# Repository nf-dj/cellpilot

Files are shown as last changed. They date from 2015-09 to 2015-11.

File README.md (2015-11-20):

# CellPilot

A controller to pilot UAV/drones via 3G/4G cellular connection.

WARNING: this version of CellPilot will soon be replaced by a new controller using TinyCom instead of Raspberry Pi (http://github.com/nfco/tinycom).

## Pictures

A view of the PCB, a Raspberry Pi "hat":

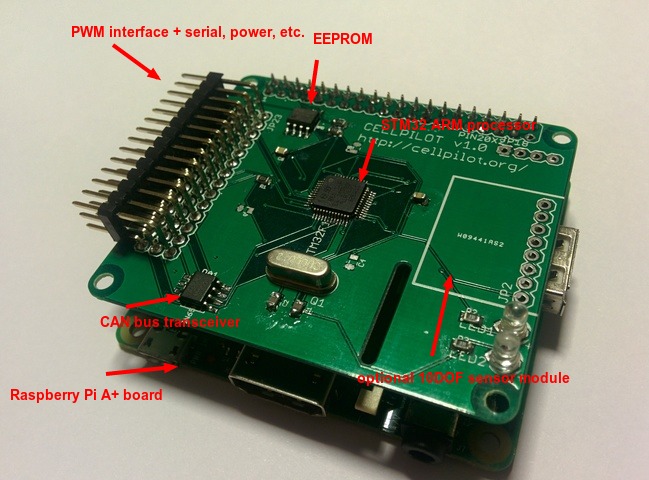
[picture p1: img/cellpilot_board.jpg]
CellPilot board


Inside a 3d-printed prototype box:

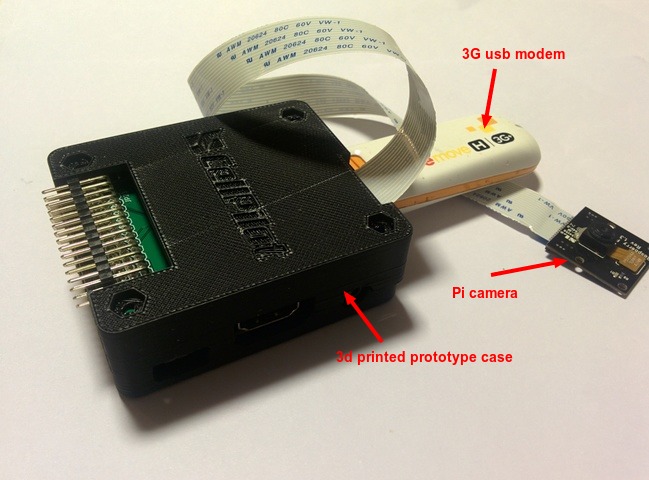
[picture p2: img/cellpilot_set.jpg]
CellPilot set


CellPilot installed on a DIY drone:

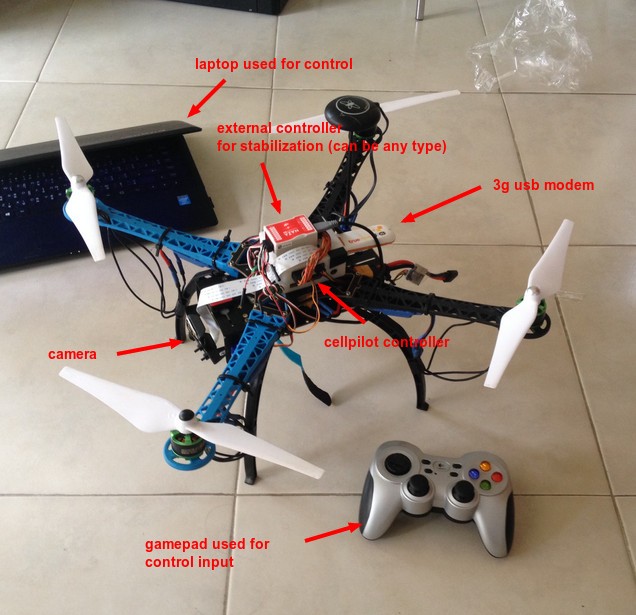
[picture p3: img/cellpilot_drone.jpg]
CellPilot drone


We still rely on an external controller for stabilization.
But a 10DOF sensor module can be installed on the CellPilot board and we can later try to do the stabilization directly on the STM32 processor of the board. (a prototype firmware to do this is already in the repository)

## Video

CellPilot test flight (64Kbps, 10fps):

CellPilot test flight (http://www.youtube.com/watch?v=GPAqMF_AkHQ)

(the strange colors in the video are due to the PiNoir camera, we will make a new video with a regular Pi camera and some vibration dampening)

## Ordering

A 3d-printed plastic case can be ordered here:
https://www.shapeways.com/shops/netforce

CellPilot case

## Contact

Send email to dj@netforce.com.

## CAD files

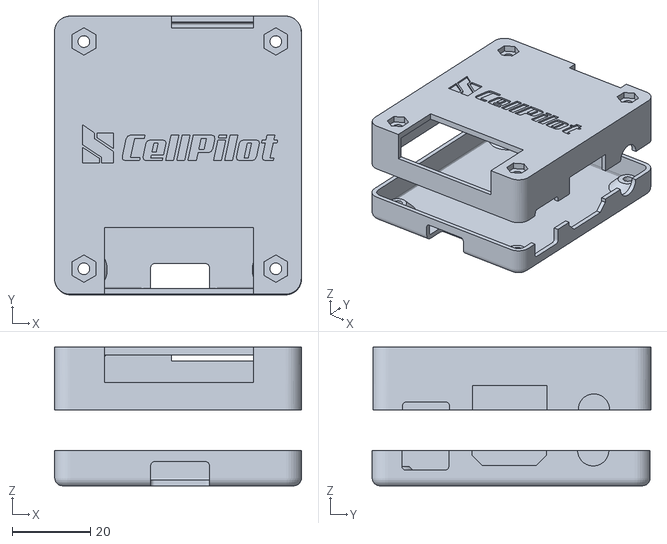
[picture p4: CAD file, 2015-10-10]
case/cellpilot_case.stl
63.1 x 71.2 x 35.4

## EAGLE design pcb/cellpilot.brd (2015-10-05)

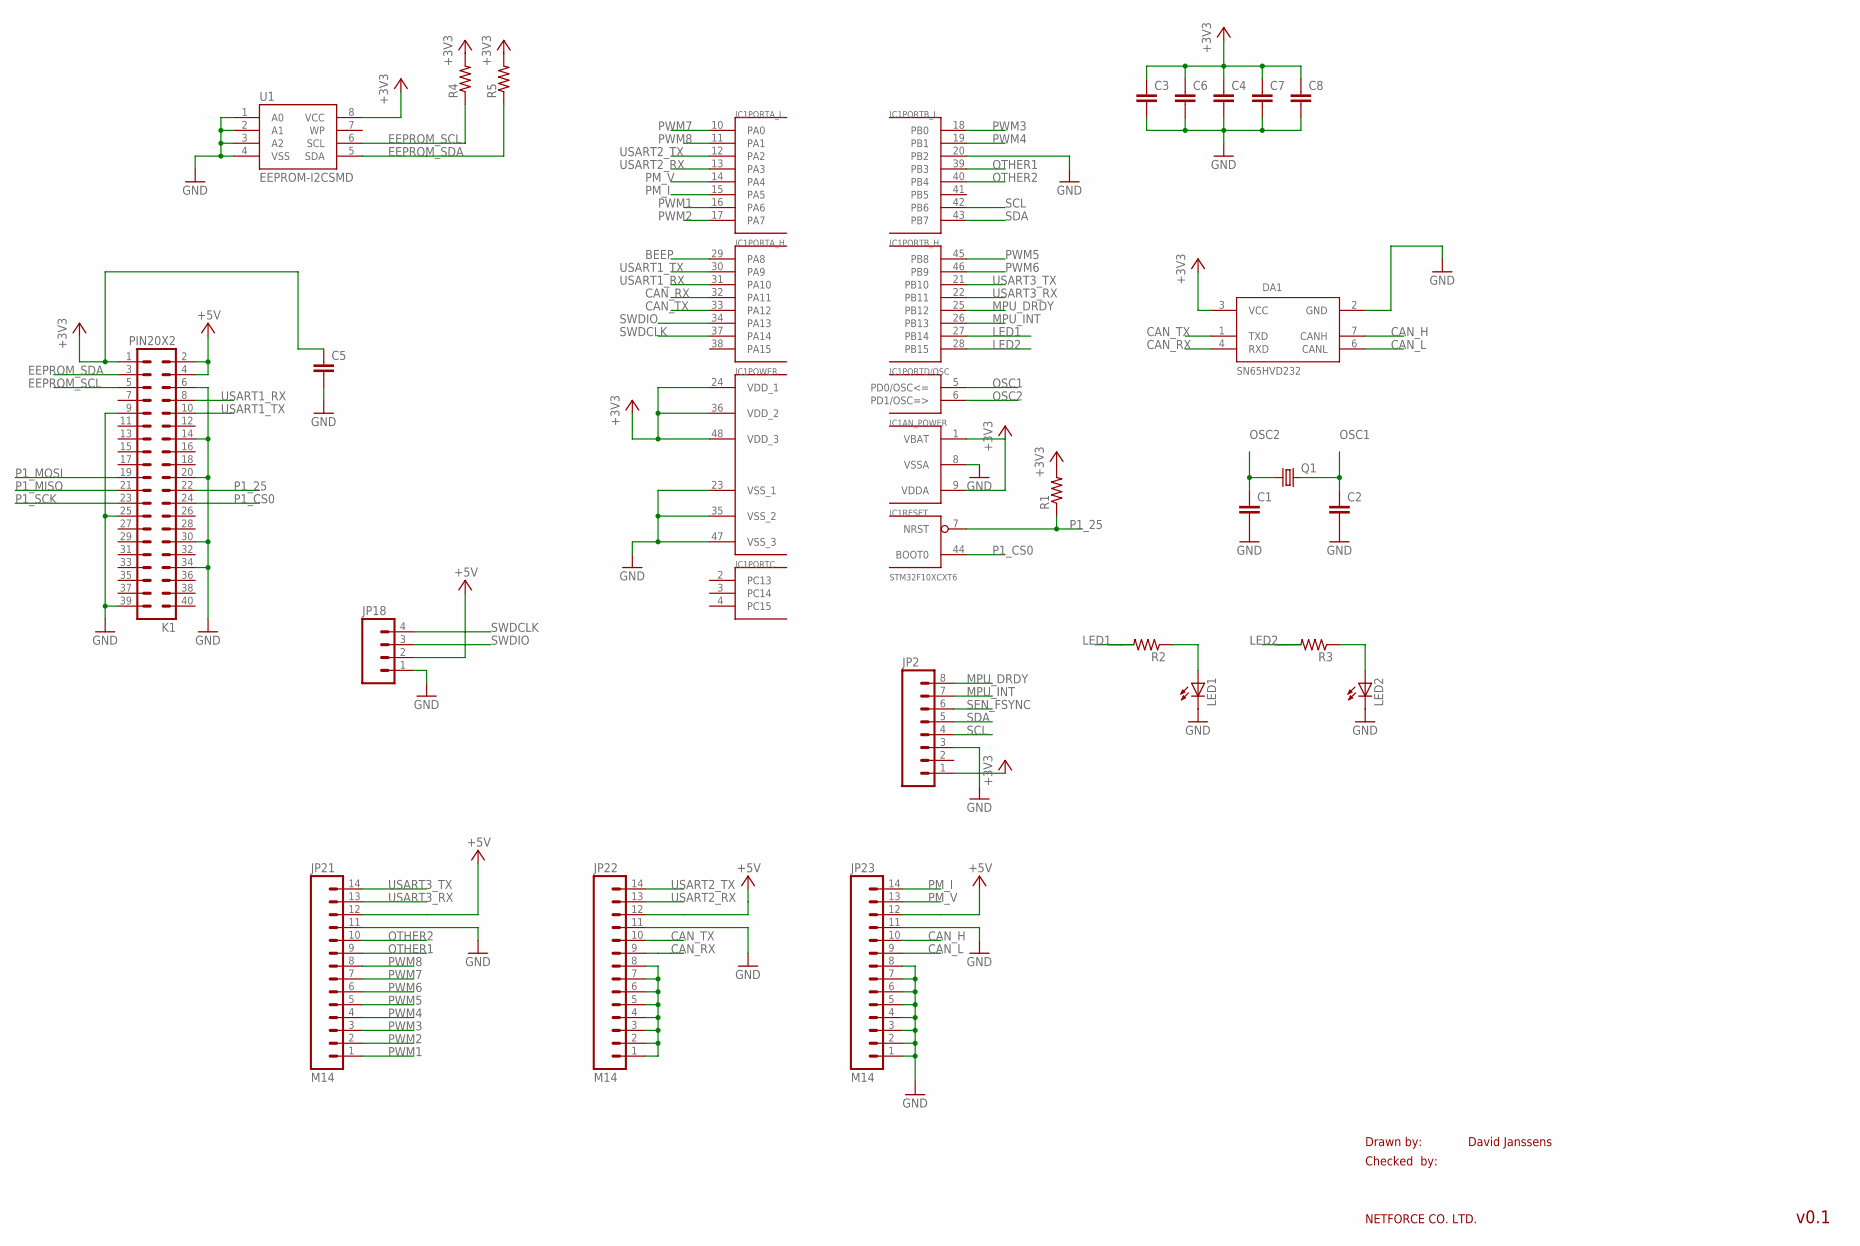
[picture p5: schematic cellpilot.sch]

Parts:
C1, C2, C3, C4, C5, C6, C7, C8: CAP0805; 0805
DA1: SN65HVD232; SO08
IC1: STM32F10XCXT6; TQFP48
JP2: M08; 1X08_ROUND
JP18: M04PTH; 1X04
JP21, JP22, JP23: M14; 1X14
K1: PIN20X2; PIN_20X2
LED1, LED2: LED3MM
Q1: CRYSTALHC49S; HC49/S
R1, R2, R3, R4, R5: RESISTOR0805-RES; 0805
U1: EEPROM-I2CSMD; SO08

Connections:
+3V3: C3.1, C4.1, C5.1, C6.1, C7.1, C8.1, DA1.3 (VCC), IC1.1 (VBAT), IC1.9 (VDDA), IC1.24 (VDD_1), IC1.36 (VDD_2), IC1.48 (VDD_3), JP2.1, K1.1, R1.2, R4.2, R5.2, U1.8 (VCC)
+5V: JP18.2, JP21.12, JP22.12, JP23.12, K1.2, K1.4
BEEP: IC1.29 (PA8)
CAN_H: DA1.7 (CANH), JP23.10
CAN_L: DA1.6 (CANL), JP23.9
CAN_RX: DA1.4 (RXD), IC1.32 (PA11), JP22.9
CAN_TX: DA1.1 (TXD), IC1.33 (PA12), JP22.10
EEPROM_SCL: K1.5, R4.1, U1.6 (SCL)
EEPROM_SDA: K1.3, R5.1, U1.5 (SDA)
GND: C1.2, C2.2, C3.2, C4.2, C5.2, C6.2, C7.2, C8.2, DA1.2 (GND), IC1.8 (VSSA), IC1.20 (PB2), IC1.23 (VSS_1), IC1.35 (VSS_2), IC1.47 (VSS_3), JP2.3, JP18.1, JP21.11, JP22.11, JP23.1, JP23.2, JP23.3, JP23.4, JP23.5, JP23.6, JP23.7, JP23.8, JP23.11, K1.6, K1.9, K1.14, K1.20, K1.25, K1.30, K1.34, K1.39, LED1.K (C), LED2.K (C), U1.1 (A0), U1.2 (A1), U1.3 (A2), U1.4 (VSS)
LED1: IC1.27 (PB14), R2.2
LED2: IC1.28 (PB15), R3.2
MPU_DRDY: IC1.25 (PB12), JP2.8
MPU_INT: IC1.26 (PB13), JP2.7
unnamed: LED1.A, R2.1
unnamed: JP22.1, JP22.2, JP22.3, JP22.4, JP22.5, JP22.6, JP22.7, JP22.8
unnamed: LED2.A, R3.1
OSC1: C2.1, IC1.5 (PD0/OSC<=), Q1.2
OSC2: C1.1, IC1.6 (PD1/OSC=>), Q1.1
OTHER1: IC1.39 (PB3), JP21.9
OTHER2: IC1.40 (PB4), JP21.10
P1_25: IC1.7 (NRST), K1.22, R1.1
P1_CS0: IC1.44 (BOOT0), K1.24
P1_MISO: K1.21
P1_MOSI: K1.19
P1_SCK: K1.23
PM_I: IC1.15 (PA5), JP23.14
PM_V: IC1.14 (PA4), JP23.13
PWM1: IC1.16 (PA6), JP21.1
PWM2: IC1.17 (PA7), JP21.2
PWM3: IC1.18 (PB0), JP21.3
PWM4: IC1.19 (PB1), JP21.4
PWM5: IC1.45 (PB8), JP21.5
PWM6: IC1.46 (PB9), JP21.6
PWM7: IC1.10 (PA0), JP21.7
PWM8: IC1.11 (PA1), JP21.8
SCL: IC1.42 (PB6), JP2.4
SDA: IC1.43 (PB7), JP2.5
SEN_FSYNC: JP2.6
SWDCLK: IC1.37 (PA14), JP18.4
SWDIO: IC1.34 (PA13), JP18.3
USART1_RX: IC1.31 (PA10), K1.8
USART1_TX: IC1.30 (PA9), K1.10
USART2_RX: IC1.13 (PA3), JP22.13
USART2_TX: IC1.12 (PA2), JP22.14
USART3_RX: IC1.22 (PB11), JP21.13
USART3_TX: IC1.21 (PB10), JP21.14

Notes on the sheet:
Drawn by:
Checked by:
NETFORCE CO. LTD.
David Janssens
v0.1

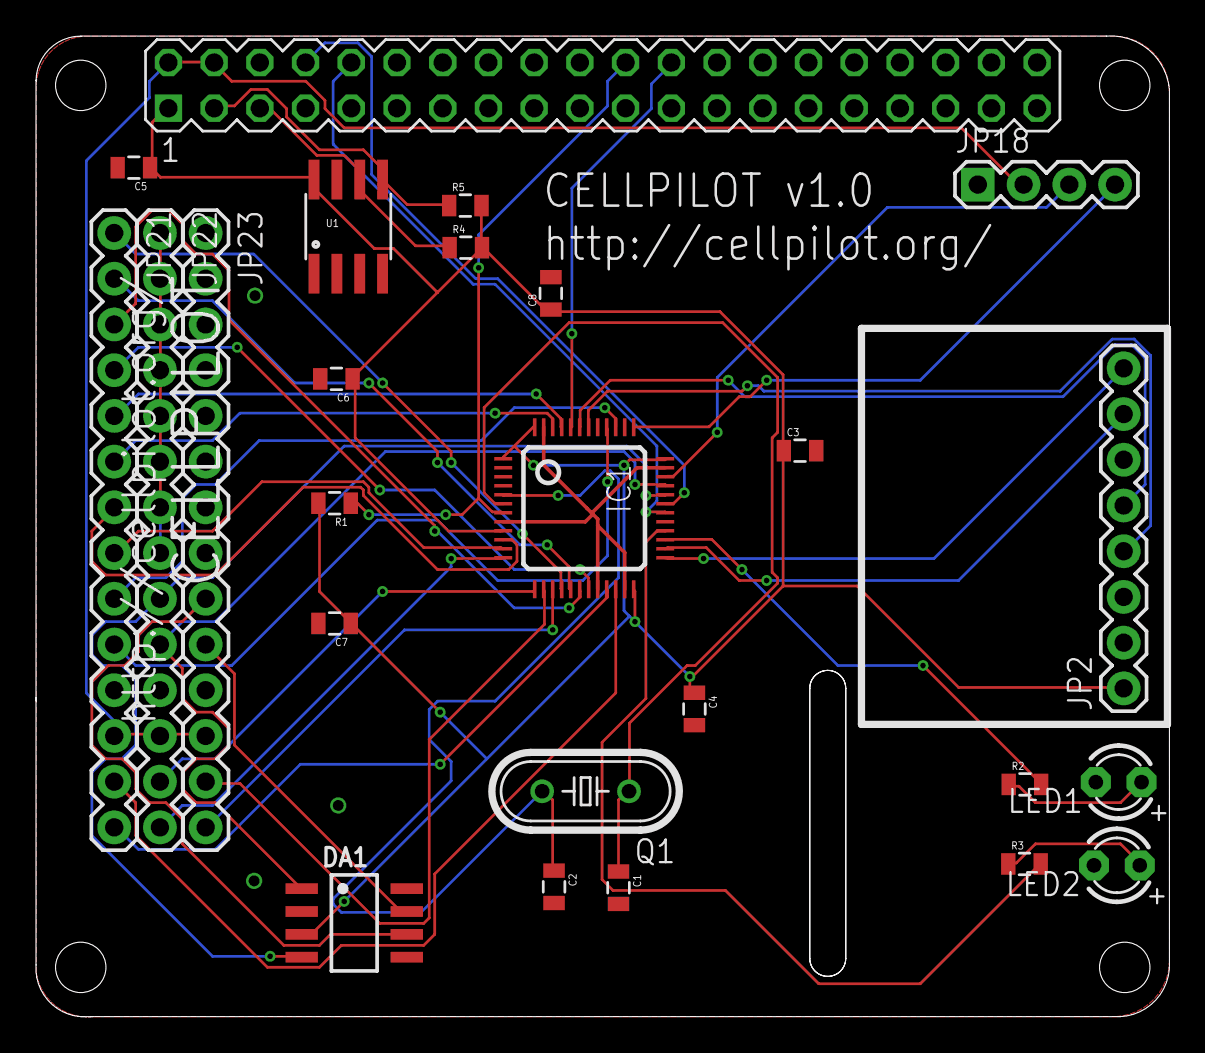
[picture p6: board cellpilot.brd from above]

Board: 2 copper layers, 63.0 x 54.5 mm, 25 parts (0 on the bottom side), 42 nets.

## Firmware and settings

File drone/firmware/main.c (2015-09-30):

/*
 * Copyright (c) 2015 Netforce Co. Ltd.
 * 
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
 * THE SOFTWARE IS PROVIDED "AS IS", WITHOUT WARRANTY OF ANY KIND,
 * EXPRESS OR IMPLIED, INCLUDING BUT NOT LIMITED TO THE WARRANTIES OF
 * MERCHANTABILITY, FITNESS FOR A PARTICULAR PURPOSE AND NONINFRINGEMENT.
 * IN NO EVENT SHALL THE AUTHORS OR COPYRIGHT HOLDERS BE LIABLE FOR ANY CLAIM,
 * DAMAGES OR OTHER LIABILITY, WHETHER IN AN ACTION OF CONTRACT, TORT OR
 * OTHERWISE, ARISING FROM, OUT OF OR IN CONNECTION WITH THE SOFTWARE OR THE USE
 * OR OTHER DEALINGS IN THE SOFTWARE.
 */

#include "stm32f10x.h"

#define CPU_FREQ 72000000
#define NUM_PWM 8
#define NO_SIGNAL_DELAY 10000

#define CTRL_NO_SIGNAL 0
#define CTRL_PWM 1
#define CTRL_ACRO 2
#define CTRL_ATTI 3
#define CTRL_GPS 4

uint8_t ctrl_mode=CTRL_NO_SIGNAL;
uint8_t prev_ctrl_mode=CTRL_NO_SIGNAL;

uint32_t clock_ms=0;

uint8_t cmd_buf[256];
uint8_t cmd_size;
uint8_t cmd_num_read;
uint32_t last_cmd_time;

#define USART_READ_CMD_HEAD 0
#define USART_READ_CMD_SIZE 1
#define USART_READ_CMD 2
#define USART_WRITE_RESP 3

uint8_t usart_mode=USART_READ_CMD_HEAD;

void init_clock() {
    SysTick_Config(CPU_FREQ/1000);
    RCC_APB2PeriphClockCmd(RCC_APB2Periph_USART1 | RCC_APB2Periph_AFIO | RCC_APB2Periph_GPIOA | RCC_APB2Periph_GPIOB, ENABLE);
    RCC_APB1PeriphClockCmd(RCC_APB1Periph_TIM3 | RCC_APB1Periph_TIM4 | RCC_APB1Periph_TIM2, ENABLE );
}
 
// USART1_TX: PA9
// USART1_RX: PA10
// LED1: PB14
// LED2: PB15
// PWM1: PA6, TIM3_CH1
// PWM2: PA7, TIM3_CH2
// PWM3: PB0, TIM3_CH3
// PWM4: PB1, TIM3_CH4
// PWM5: PB8, TIM4_CH3
// PWM6: PB9, TIM4_CH4
// PWM7: PA0, TIM2_CH1
// PWM8: PA1, TIM2_CH2

void init_gpio() {
    GPIO_InitTypeDef gpio_init_struct;

    // USART1_TX
    gpio_init_struct.GPIO_Pin = GPIO_Pin_9;
    gpio_init_struct.GPIO_Speed = GPIO_Speed_50MHz;
    gpio_init_struct.GPIO_Mode = GPIO_Mode_AF_PP;
    GPIO_Init(GPIOA, &gpio_init_struct);

    // USART1_RX
    gpio_init_struct.GPIO_Pin = GPIO_Pin_10;
    gpio_init_struct.GPIO_Speed = GPIO_Speed_50MHz;
    gpio_init_struct.GPIO_Mode = GPIO_Mode_IN_FLOATING;
    GPIO_Init(GPIOA, &gpio_init_struct);

    // LED1
    gpio_init_struct.GPIO_Pin = GPIO_Pin_14;
    gpio_init_struct.GPIO_Speed = GPIO_Speed_50MHz;
    gpio_init_struct.GPIO_Mode = GPIO_Mode_Out_PP;
    GPIO_Init(GPIOB, &gpio_init_struct);

    // LED2
    gpio_init_struct.GPIO_Pin = GPIO_Pin_15;
    gpio_init_struct.GPIO_Speed = GPIO_Speed_50MHz;
    gpio_init_struct.GPIO_Mode = GPIO_Mode_Out_PP;
    GPIO_Init(GPIOB, &gpio_init_struct);

    // PWM1
    gpio_init_struct.GPIO_Pin =  GPIO_Pin_6;
    gpio_init_struct.GPIO_Speed = GPIO_Speed_50MHz;
    gpio_init_struct.GPIO_Mode = GPIO_Mode_AF_PP;
    GPIO_Init(GPIOA, &gpio_init_struct);
 
    // PWM2
    gpio_init_struct.GPIO_Pin =  GPIO_Pin_7;
    gpio_init_struct.GPIO_Speed = GPIO_Speed_50MHz;
    gpio_init_struct.GPIO_Mode = GPIO_Mode_AF_PP;
    GPIO_Init(GPIOA, &gpio_init_struct);
 
    // PWM3
    gpio_init_struct.GPIO_Pin =  GPIO_Pin_0;
    gpio_init_struct.GPIO_Speed = GPIO_Speed_50MHz;
    gpio_init_struct.GPIO_Mode = GPIO_Mode_AF_PP;
    GPIO_Init(GPIOB, &gpio_init_struct);
 
    // PWM4
    gpio_init_struct.GPIO_Pin =  GPIO_Pin_1;
    gpio_init_struct.GPIO_Speed = GPIO_Speed_50MHz;
    gpio_init_struct.GPIO_Mode = GPIO_Mode_AF_PP;
    GPIO_Init(GPIOB, &gpio_init_struct);
 
    // PWM5
    gpio_init_struct.GPIO_Pin =  GPIO_Pin_8;
    gpio_init_struct.GPIO_Speed = GPIO_Speed_50MHz;
    gpio_init_struct.GPIO_Mode = GPIO_Mode_AF_PP;
    GPIO_Init(GPIOB, &gpio_init_struct);
 
    // PWM6
    gpio_init_struct.GPIO_Pin =  GPIO_Pin_9;
    gpio_init_struct.GPIO_Speed = GPIO_Speed_50MHz;
    gpio_init_struct.GPIO_Mode = GPIO_Mode_AF_PP;
    GPIO_Init(GPIOB, &gpio_init_struct);
 
    // PWM7
    gpio_init_struct.GPIO_Pin =  GPIO_Pin_0;
    gpio_init_struct.GPIO_Speed = GPIO_Speed_50MHz;
    gpio_init_struct.GPIO_Mode = GPIO_Mode_AF_PP;
    GPIO_Init(GPIOA, &gpio_init_struct);
 
    // PWM8
    gpio_init_struct.GPIO_Pin =  GPIO_Pin_1;
    gpio_init_struct.GPIO_Speed = GPIO_Speed_50MHz;
    gpio_init_struct.GPIO_Mode = GPIO_Mode_AF_PP;
    GPIO_Init(GPIOA, &gpio_init_struct);
}
 
void init_usart() {
    USART_InitTypeDef usart_init_struct;
    USART_Cmd(USART1, ENABLE);  
    usart_init_struct.USART_BaudRate = 115200;   
    usart_init_struct.USART_WordLength = USART_WordLength_8b;  
    usart_init_struct.USART_StopBits = USART_StopBits_1;   
    usart_init_struct.USART_Parity = USART_Parity_No ;
    usart_init_struct.USART_Mode = USART_Mode_Rx | USART_Mode_Tx;
    usart_init_struct.USART_HardwareFlowControl = USART_HardwareFlowControl_None;
    USART_Init(USART1, &usart_init_struct);
    USART_ITConfig(USART1, USART_IT_RXNE, ENABLE);
    NVIC_EnableIRQ(USART1_IRQn);
}

void init_pwm() {
    TIM_TimeBaseInitTypeDef timebase_init_struct;
    TIM_OCInitTypeDef oc_init_struct;

    TIM_TimeBaseStructInit(&timebase_init_struct);
    timebase_init_struct.TIM_ClockDivision = 0;
    timebase_init_struct.TIM_Period = 2500 - 1;
    timebase_init_struct.TIM_Prescaler = 72 - 1; // 72MHz/400Hz/2500=72
    TIM_TimeBaseInit(TIM3, &timebase_init_struct);
    TIM_TimeBaseInit(TIM4, &timebase_init_struct);
    TIM_TimeBaseInit(TIM2, &timebase_init_struct);

    TIM_OCStructInit(&oc_init_struct);
    oc_init_struct.TIM_OCMode = TIM_OCMode_PWM1;
    oc_init_struct.TIM_OutputState = TIM_OutputState_Enable;
    oc_init_struct.TIM_Pulse = 0;
    // PWM1: TIM3_CH1
    TIM_OC1Init(TIM3, &oc_init_struct);
    // PWM2: TIM3_CH2
    TIM_OC2Init(TIM3, &oc_init_struct);
    // PWM3: TIM3_CH3
    TIM_OC3Init(TIM3, &oc_init_struct);
    // PWM4: TIM3_CH4
    TIM_OC4Init(TIM3, &oc_init_struct);
    // PWM5: TIM4_CH3
    TIM_OC3Init(TIM4, &oc_init_struct);
    // PWM6: TIM4_CH4
    TIM_OC4Init(TIM4, &oc_init_struct);
    // PWM1: TIM2_CH1
    TIM_OC1Init(TIM2, &oc_init_struct);
    // PWM2: TIM2_CH2
    TIM_OC2Init(TIM2, &oc_init_struct);

    TIM_Cmd(TIM3, ENABLE);
    TIM_Cmd(TIM4, ENABLE);
    TIM_Cmd(TIM2, ENABLE);
}

void set_led(uint8_t led_no, uint8_t state) {
    if (led_no==0) {
        if (state) {
            GPIO_SetBits(GPIOB, GPIO_Pin_14);
        } else {
            GPIO_ResetBits(GPIOB, GPIO_Pin_14);
        }
    } else if (led_no==1) {
        if (state) {
            GPIO_SetBits(GPIOB, GPIO_Pin_15);
        } else {
            GPIO_ResetBits(GPIOB, GPIO_Pin_15);
        }
    }
}

void set_pwm(uint8_t chan, uint16_t dur) {
    if (dur>2000) return;
    if (chan==0) {
        TIM3->CCR1=dur;
    } else if (chan==1) {
        TIM3->CCR2=dur;
    } else if (chan==2) {
        TIM3->CCR3=dur;
    } else if (chan==3) {
        TIM3->CCR4=dur;
    } else if (chan==4) {
        TIM4->CCR3=dur;
    } else if (chan==5) {
        TIM4->CCR4=dur;
    } else if (chan==6) {
        TIM2->CCR1=dur;
    } else if (chan==7) {
        TIM2->CCR2=dur;
    }
}

void signal_lost() {
    int i;
    prev_ctrl_mode=ctrl_mode;
    ctrl_mode=CTRL_NO_SIGNAL;
    for (i=0; i<NUM_PWM; i++) {
        set_pwm(i,0);
    }
    set_led(0,1);
}

int process_command() {
    int resp_size;
    last_cmd_time=clock_ms;
    if (ctrl_mode==CTRL_NO_SIGNAL) {
        ctrl_mode=prev_ctrl_mode;
        set_led(0,0);
    }
    char cmd=cmd_buf[0];
    if (cmd=='P') {
        uint8_t chan=cmd_buf[1];
        uint16_t dur=(cmd_buf[2]<<8)|cmd_buf[3];
        ctrl_mode=CTRL_PWM;
        set_pwm(chan,dur);
        resp_size=0;
    } else if (cmd=='L') {
        uint8_t led_no=cmd_buf[1];
        uint16_t state=cmd_buf[2];
        set_led(led_no,state);
        resp_size=0;
    } else {
        resp_size=-1;
    }
    return resp_size;
}
 
void USART1_IRQHandler() {
    uint8_t c;
    if (USART_GetITStatus(USART1, USART_IT_RXNE)!=RESET) {
        c=USART_ReceiveData(USART1);
        if (usart_mode==USART_READ_CMD_HEAD) {
            if (c=='C') {
                usart_mode=USART_READ_CMD_SIZE;
            }
        } else if (usart_mode==USART_READ_CMD_SIZE) {
            cmd_size=c;
            cmd_num_read=0;
            usart_mode=USART_READ_CMD;
        } else if (usart_mode==USART_READ_CMD) {
            cmd_buf[cmd_num_read++]=c;
            if (cmd_num_read>=cmd_size) {
                process_command();
                usart_mode=USART_READ_CMD_HEAD;
            }
        }
    }
}

void SysTick_Handler() {
    clock_ms+=1;
    if (clock_ms-last_cmd_time>NO_SIGNAL_DELAY && ctrl_mode!=CTRL_NO_SIGNAL) {
        signal_lost();
    }
}

int main() {
    init_clock();
    init_gpio();
    init_usart();
    init_pwm();
    while(1) {}
}

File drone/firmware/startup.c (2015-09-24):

#include "stm32f10x.h"

typedef void( *const intfunc )( void );
 
#define WEAK __attribute__ ((weak))
 
extern unsigned long _etext;
extern unsigned long _sidata;
extern unsigned long _sdata;
extern unsigned long _edata;
extern unsigned long _sbss;
extern unsigned long _ebss;
extern unsigned long _estack;

void Reset_Handler(void) __attribute__((__interrupt__));
void __Init_Data(void);
void SystemInit (void);
void Default_Handler(void);
 
extern int main(void);
 
/* Init Data
 * Loads data from addresses defined in linker file into RAM
 * Zero bss (statically allocated uninitialized variables)
 */
void __Init_Data(void) {
    unsigned long *src, *dst;
    /* copy the data segment into ram */
    src = &_sidata;
    dst = &_sdata;
    if (src != dst)
        while(dst < &_edata)
            *(dst++) = *(src++);
 
    /* zero the bss segment */
    dst = &_sbss;
    while(dst < &_ebss)
        *(dst++) = 0;
}
 
/* This function is straight from the system_stm32f10x.c library file and
 * is called within the startup file:
 * 1. After each device reset the HSI is used as System clock source.
 * 2. This function assumes that an external 8MHz crystal is used to drive the System clock.
 */
void SystemInit (void)
{
    /* Reset the RCC clock configuration to the default reset state */
    /* Set HSION bit */
    RCC->CR |= (uint32_t)0x00000001;
    /* Reset SW, HPRE, PPRE1, PPRE2, ADCPRE and MCO bits */
    RCC->CFGR &= (uint32_t)0xF8FF0000;
    /* Reset HSEON, CSSON and PLLON bits */
    RCC->CR &= (uint32_t)0xFEF6FFFF;
    /* Reset HSEBYP bit */
    RCC->CR &= (uint32_t)0xFFFBFFFF;
    /* Disable all interrupts and clear pending bits  */
    RCC->CIR = 0x009F0000;
    /* Enable HSE */
    RCC->CR |= ((uint32_t)RCC_CR_HSEON);
    /* Wait till HSE is ready */
    do
    {
    } while ((RCC->CR & RCC_CR_HSERDY) == RESET);
    /* Configure the Flash Latency cycles and enable prefetch buffer */
    FLASH->ACR = FLASH_ACR_PRFTBE | FLASH_ACR_LATENCY_2;
    /* Configure the System clock frequency, HCLK, PCLK2 and PCLK1 prescalers */
    /* HCLK = SYSCLK, PCLK2 = HCLK, PCLK1 = HCLK / 2
     * If crystal is 16MHz, add in PLLXTPRE flag to prescale by 2
     */
    RCC->CFGR = (uint32_t)( RCC_CFGR_HPRE_DIV1  |
                            RCC_CFGR_PPRE2_DIV1 |
                            RCC_CFGR_PPRE1_DIV2 |
                            RCC_CFGR_PLLSRC_HSE |
                            RCC_CFGR_PLLMULL9 );
    /* Enable PLL */
    RCC->CR |= RCC_CR_PLLON;
    /* Wait till PLL is ready */
    while ((RCC->CR & RCC_CR_PLLRDY) == 0)
    {
    }
    /* Select PLL as system clock source */
    RCC->CFGR |= (uint32_t)RCC_CFGR_SW_PLL;
    /* Wait till PLL is used as system clock source */
    while ((RCC->CFGR & (uint32_t)RCC_CFGR_SWS) != (uint32_t)0x08)
    {
    }
}
 
void Reset_Handler(void) {
    /* Initialize data and bss */
    __Init_Data();
    extern uint32_t _isr_vectors_offs;
    SCB->VTOR = 0x08000000 | ((uint32_t)&_isr_vectors_offs & (uint32_t)0x1FFFFF80);
    SystemInit();
    while(1)
    {
      __Init_Data();
      main();
    }
    while(1) {}
}
 
void WEAK NMI_Handler(void);
void WEAK HardFault_Handler(void);
void WEAK MemManage_Handler(void);
void WEAK BusFault_Handler(void);
void WEAK UsageFault_Handler(void);
void WEAK MemManage_Handler(void);
void WEAK SVC_Handler(void);
void WEAK DebugMon_Handler(void);
void WEAK PendSV_Handler(void);
void WEAK SysTick_Handler(void);
 
void WEAK WWDG_IRQHandler(void);
void WEAK PVD_IRQHandler(void);
void WEAK TAMPER_IRQHandler(void);
void WEAK RTC_IRQHandler(void);
void WEAK FLASH_IRQHandler(void);
void WEAK RCC_IRQHandler(void);
void WEAK EXTI0_IRQHandler(void);
void WEAK EXTI1_IRQHandler(void);
void WEAK EXTI2_IRQHandler(void);
void WEAK EXTI3_IRQHandler(void);
void WEAK EXTI4_IRQHandler(void);
void WEAK DMA1_Channel1_IRQHandler(void);
void WEAK DMA1_Channel2_IRQHandler(void);
void WEAK DMA1_Channel3_IRQHandler(void);
void WEAK DMA1_Channel4_IRQHandler(void);
void WEAK DMA1_Channel5_IRQHandler(void);
void WEAK DMA1_Channel6_IRQHandler(void);
void WEAK DMA1_Channel7_IRQHandler(void);
void WEAK ADC1_2_IRQHandler(void);
void WEAK USB_HP_CAN1_TX_IRQHandler(void);
void WEAK USB_LP_CAN1_RX0_IRQHandler(void);
void WEAK CAN1_RX1_IRQHandler(void);
void WEAK CAN1_SCE_IRQHandler(void);
void WEAK EXTI9_5_IRQHandler(void);
void WEAK TIM1_BRK_IRQHandler(void);
void WEAK TIM1_UP_IRQHandler(void);
void WEAK TIM1_TRG_COM_IRQHandler(void);
void WEAK TIM1_CC_IRQHandler(void);
void WEAK TIM2_IRQHandler(void);
void WEAK TIM3_IRQHandler(void);
void WEAK TIM4_IRQHandler(void);
void WEAK I2C1_EV_IRQHandler(void);
void WEAK I2C1_ER_IRQHandler(void);
void WEAK I2C2_EV_IRQHandler(void);
void WEAK I2C2_ER_IRQHandler(void);
void WEAK SPI1_IRQHandler(void);
void WEAK SPI2_IRQHandler(void);
void WEAK USART1_IRQHandler(void);
void WEAK USART2_IRQHandler(void);
void WEAK USART3_IRQHandler(void);
void WEAK EXTI15_10_IRQHandler(void);
void WEAK RTCAlarm_IRQHandler(void);
void WEAK USBWakeUp_IRQHandler(void);
void WEAK TIM8_BRK_IRQHandler(void);
void WEAK TIM8_UP_IRQHandler(void);
void WEAK TIM8_TRG_COM_IRQHandler(void);
void WEAK TIM8_CC_IRQHandler(void);
void WEAK ADC3_IRQHandler(void);
void WEAK FSMC_IRQHandler(void);
void WEAK SDIO_IRQHandler(void);
void WEAK TIM5_IRQHandler(void);
void WEAK SPI3_IRQHandler(void);
void WEAK UART4_IRQHandler(void);
void WEAK UART5_IRQHandler(void);
void WEAK TIM6_IRQHandler(void);
void WEAK TIM7_IRQHandler(void);
void WEAK DMA2_Channel1_IRQHandler(void);
void WEAK DMA2_Channel2_IRQHandler(void);
void WEAK DMA2_Channel3_IRQHandler(void);
void WEAK DMA2_Channel4_5_IRQHandler(void);
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

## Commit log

2015-09-24 add stm32loader
2015-10-03 add yaw control on gamepad
2015-10-04 add case file
2015-10-04 update pcb
    [raspilot.brd]
2015-10-05 rename to cellpilot, because found different project named raspilot...
    [cellpilot.brd, cellpilot.sch, cellpilot_case.stl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]
2015-10-05 move connector
    [cellpilot.brd, cellpilot.sch]
2015-10-06 update case
2015-10-10 impove case
    [cellpilot_case.stl]

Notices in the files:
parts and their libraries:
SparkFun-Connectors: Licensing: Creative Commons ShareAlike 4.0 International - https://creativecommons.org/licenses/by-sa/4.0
